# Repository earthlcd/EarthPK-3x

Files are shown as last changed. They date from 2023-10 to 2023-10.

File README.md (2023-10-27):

# EarthPK-3x Pico Pi Breakout Board for the 3x PCB



These are the design file for the EarthPK-3x Pico Pi Breakout Board that can be used with EarthLCD ezLCD-3x smart LCD's such asthe 3.5" ezLCD-303 and the ezLCD-304. Also this board with the mating DF-11 connector and the bare PCB along with a a bundled 4.3" ezLCD-3x is below: 

[ezLCD-3043-PK](https://earthlcd.com/products/ezlcd-3043-pk)

The arduino library to use the arduino IDE with this is below:

[arLCD Library](https://github.com/earthlcd/arLCDLib)

Schematic:
[REV-X2](https://github.com/earthlcd/EarthPK-3x/blob/master/schematics/ezLCD-303-PicoPi-Breakout-Board-REV-X2.pdf)

QuickStart Guide (coming soon)

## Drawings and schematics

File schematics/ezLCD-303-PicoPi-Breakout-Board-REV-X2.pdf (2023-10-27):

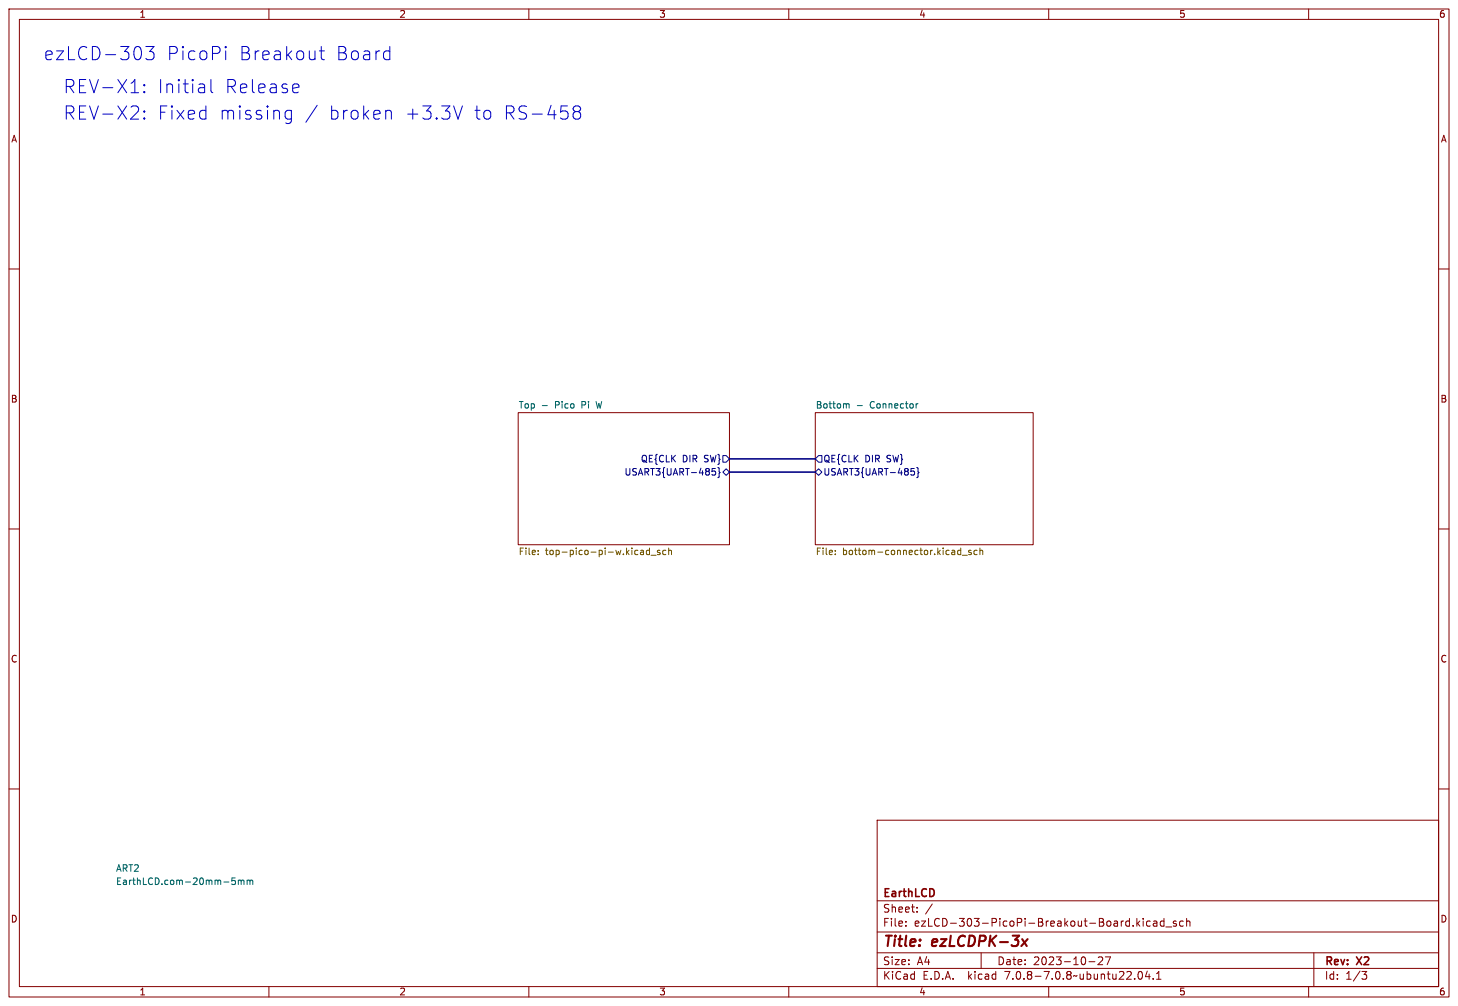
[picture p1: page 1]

QE{CLK DIR SW} Bottom - Connector File: bottom-connector.kicad_sch ART2 EarthLCD.com-20mm-5mm

QE{CLK DIR SW}
USART3{UART-485}

File: top-pico-pi-w.kicad_sch

File: ezLCD-303-PicoPi-Breakout-Board.kicad_sch Sheet: / EarthLCD

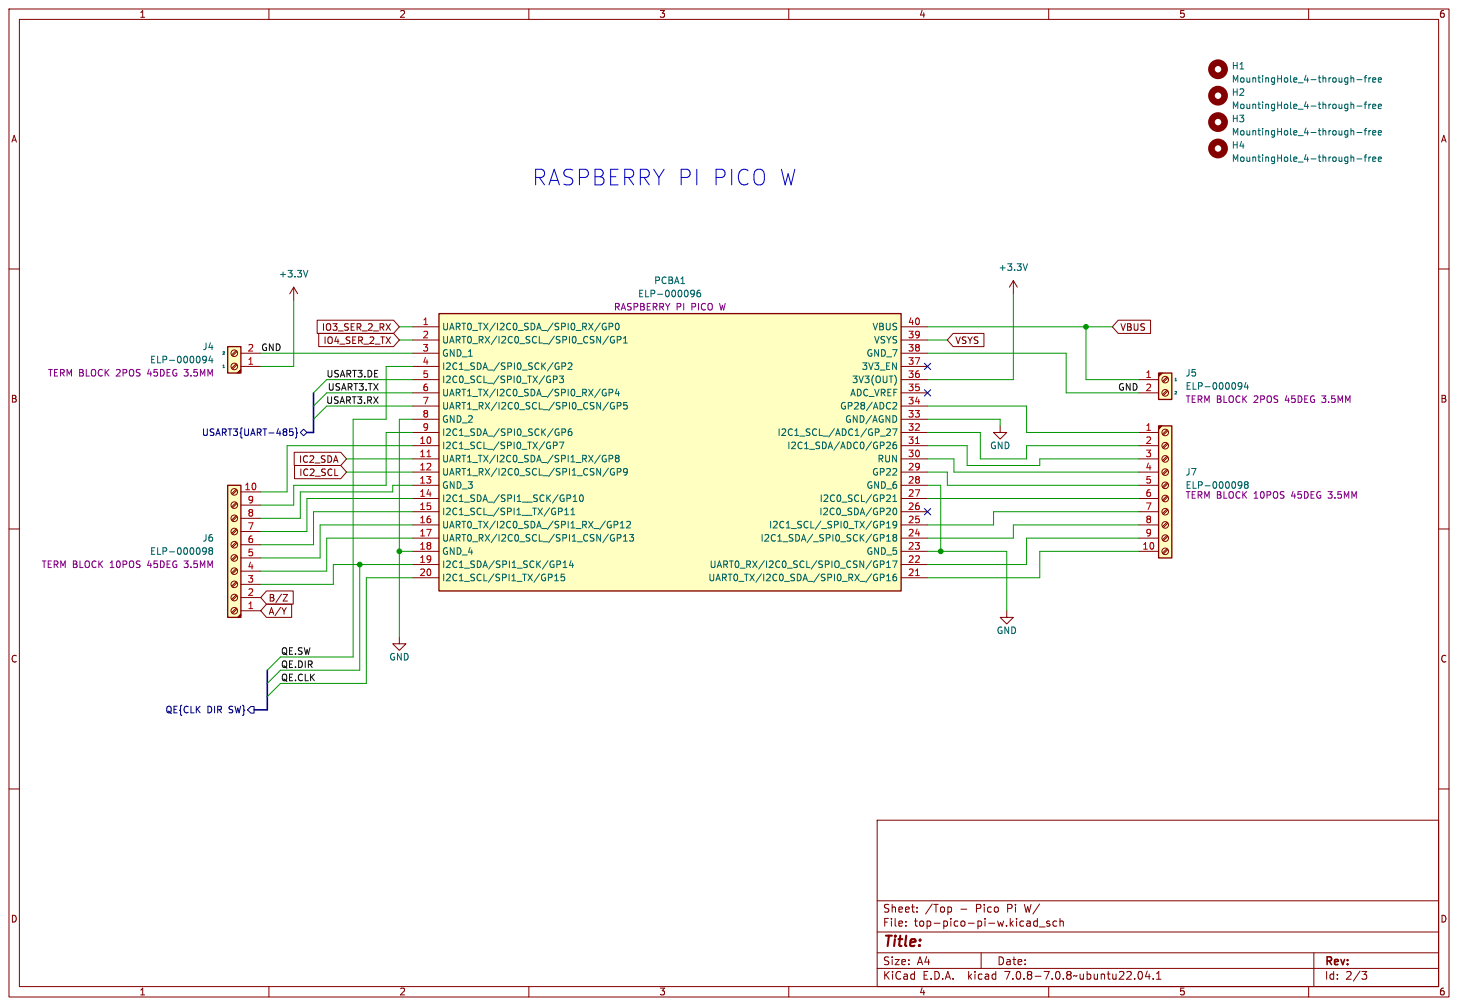
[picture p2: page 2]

H1 MountingHole_4-through-free H3 MountingHole_4-through-free H4 MountingHole_4-through-free H2 MountingHole_4-through-free

IC2_SDA QE.DIR QE.SW

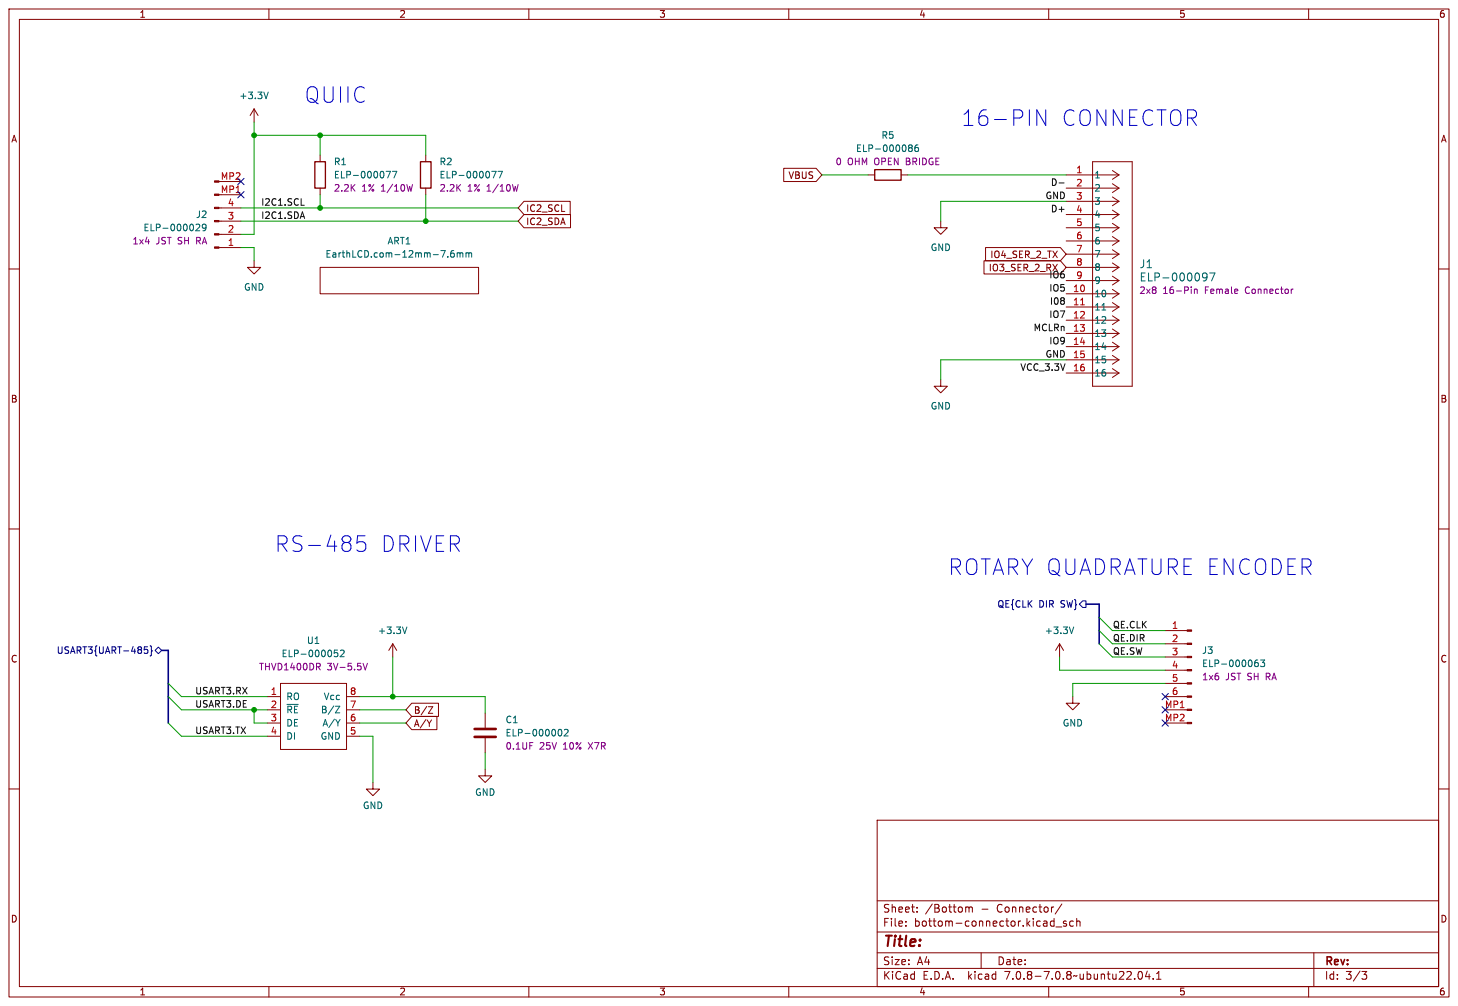
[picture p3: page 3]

QE{CLK DIR SW}

1x6 JST SH RA USART3{UART-485}

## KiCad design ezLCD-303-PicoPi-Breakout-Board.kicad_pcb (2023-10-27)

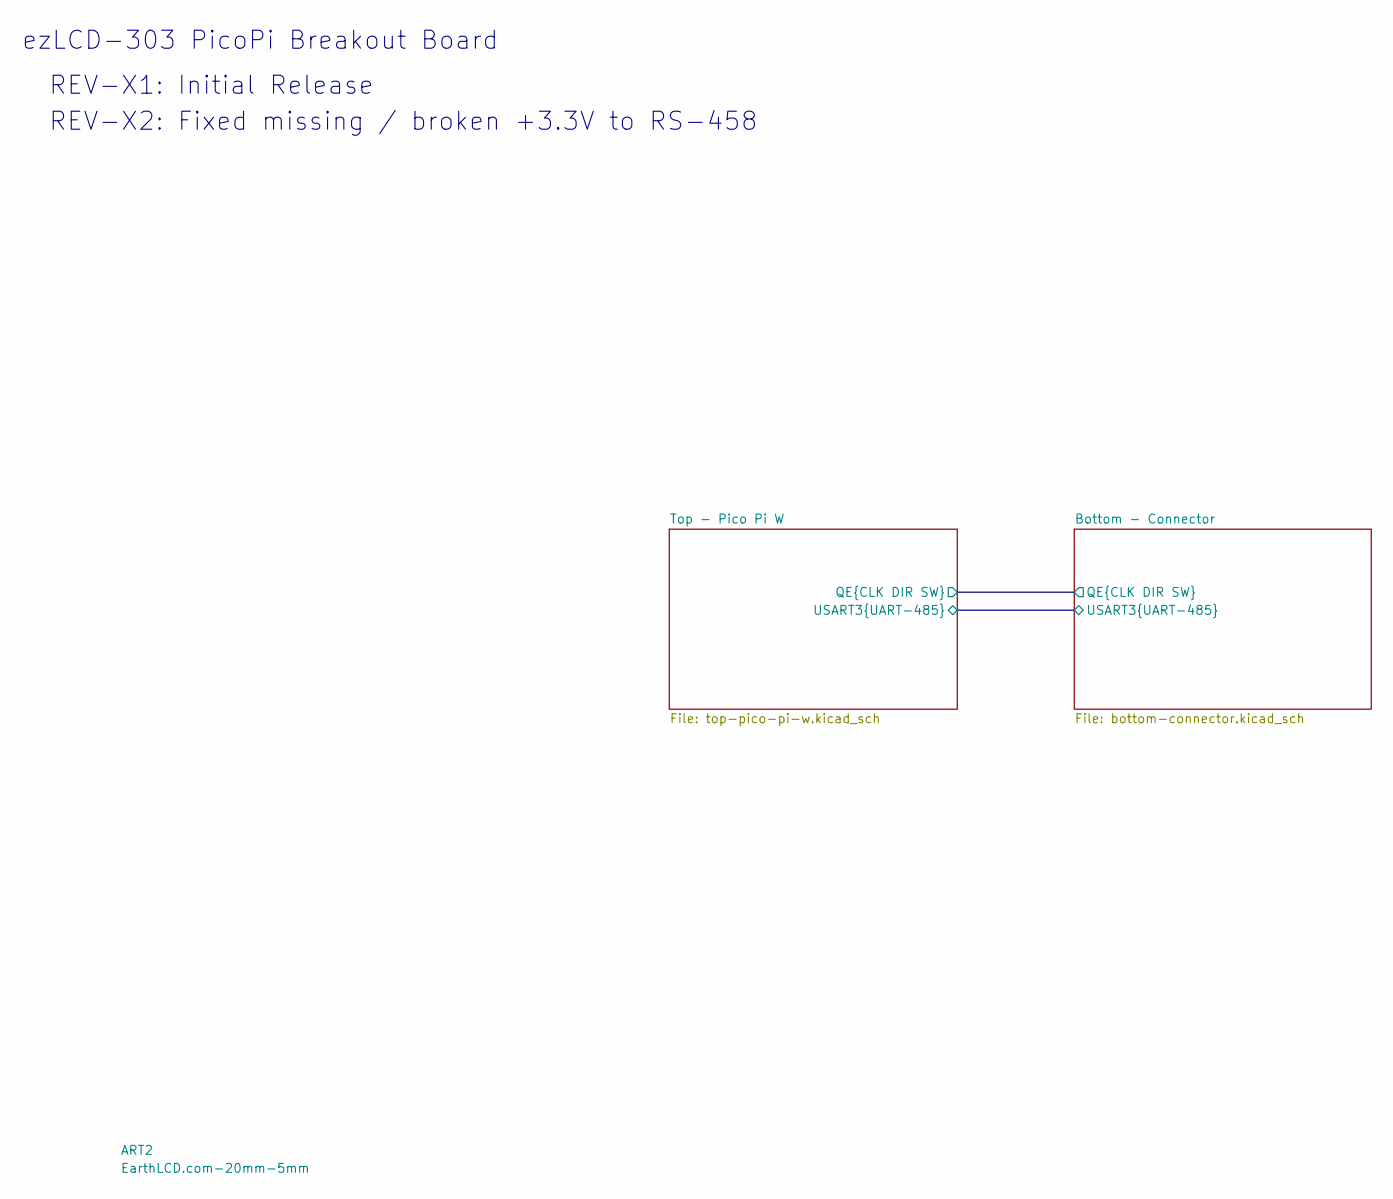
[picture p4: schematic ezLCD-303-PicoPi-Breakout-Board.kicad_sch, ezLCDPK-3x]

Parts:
ART2: EarthLCD.com-20mm-5mm; EarthLCD20mmX5mm

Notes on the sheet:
ezLCD-303 PicoPi Breakout Board
REV-X2: Fixed missing / broken +3.3V to RS-458
REV-X1: Initial Release

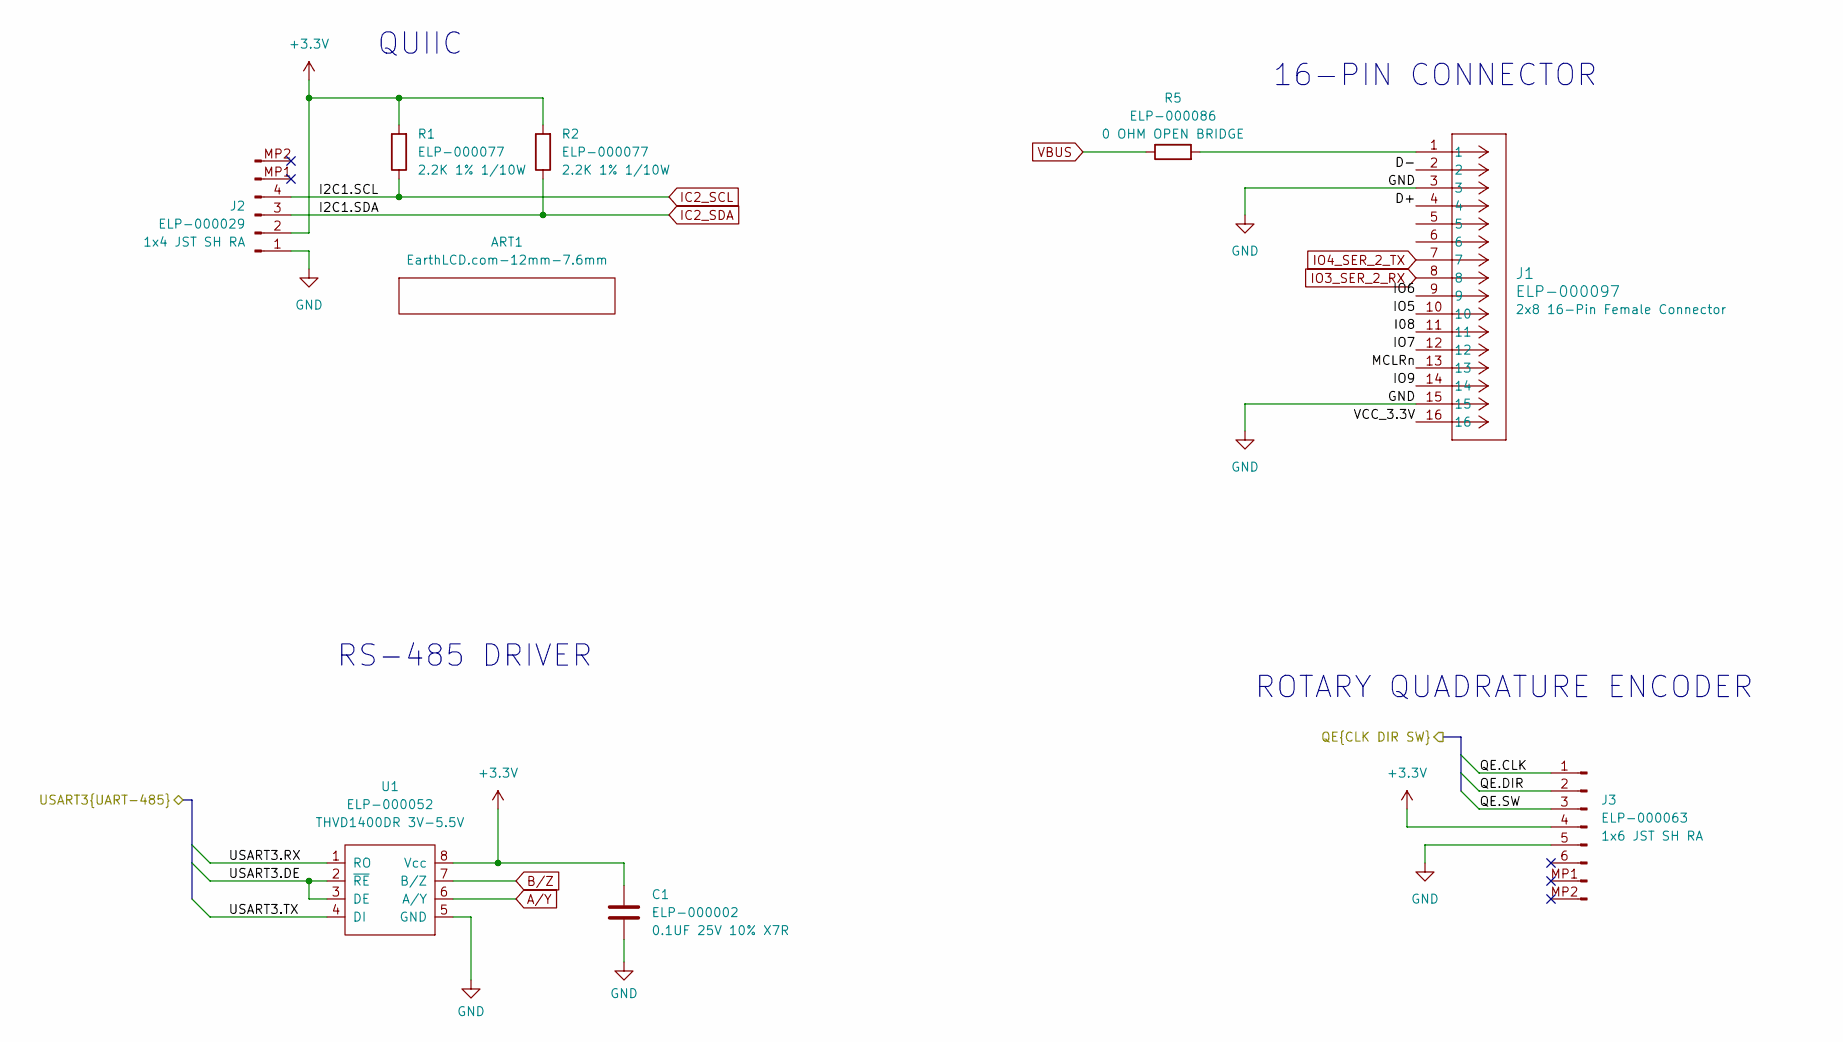
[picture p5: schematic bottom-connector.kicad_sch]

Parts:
ART1: EarthLCD.com-12mm-7.6mm; SparkFun-QWICC-Logo-4mm_x_1
C1: ELP-000002; C_0402_1005Metric
J1: ELP-000097
J2: ELP-000029; ELP-000029_JST_SH_SM04B-SRSS-TB_1x04-1MP_P1.00mm_Horizontal
J3: ELP-000063; ELP-000063_JST_SH_SM06B-SRSS-TB_1x06-1MP_P1.00mm_Horizontal
R1, R2: ELP-000077; R_0603_1608Metric
R5: ELP-000086
U1: ELP-000052; SO-8

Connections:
+3.3V: C1.1, J2.2, J3.4, R1.2, R2.2, U1.8 (Vcc); also elsewhere on the board
/Bottom - Connector/D+: J1.4
/Bottom - Connector/D-: J1.2
/Bottom - Connector/I08: J1.11
/Bottom - Connector/IO5: J1.10
/Bottom - Connector/IO6: J1.9
/Bottom - Connector/IO7: J1.12
/Bottom - Connector/IO9: J1.14
/Bottom - Connector/MCLRn: J1.13
/Bottom - Connector/QE.CLK: J3.1; also elsewhere on the board
/Bottom - Connector/QE.DIR: J3.2; also elsewhere on the board
/Bottom - Connector/QE.SW: J3.3; also elsewhere on the board
/Bottom - Connector/USART3.DE: U1.2 (~RE), U1.3 (DE)
/Bottom - Connector/USART3.RX: U1.1 (RO)
/Bottom - Connector/USART3.TX: U1.4 (DI)
/Bottom - Connector/VCC_3.3V: J1.16
A/Y: U1.6 (A/Y); also elsewhere on the board
B/Z: U1.7 (B/Z); also elsewhere on the board
GND: C1.2, J1.3, J1.15, J2.1, J3.5, U1.5 (GND); also elsewhere on the board
IC2_SCL: J2.4, R1.1; also elsewhere on the board
IC2_SDA: J2.3, R2.1; also elsewhere on the board
IO3_SER_2_RX: J1.8; also elsewhere on the board
IO4_SER_2_TX: J1.7; also elsewhere on the board
unnamed: J1.1, R5.2
VBUS: R5.1; also elsewhere on the board

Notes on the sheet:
RS-485 DRIVER
ROTARY QUADRATURE ENCODER
QUIIC
16-PIN CONNECTOR

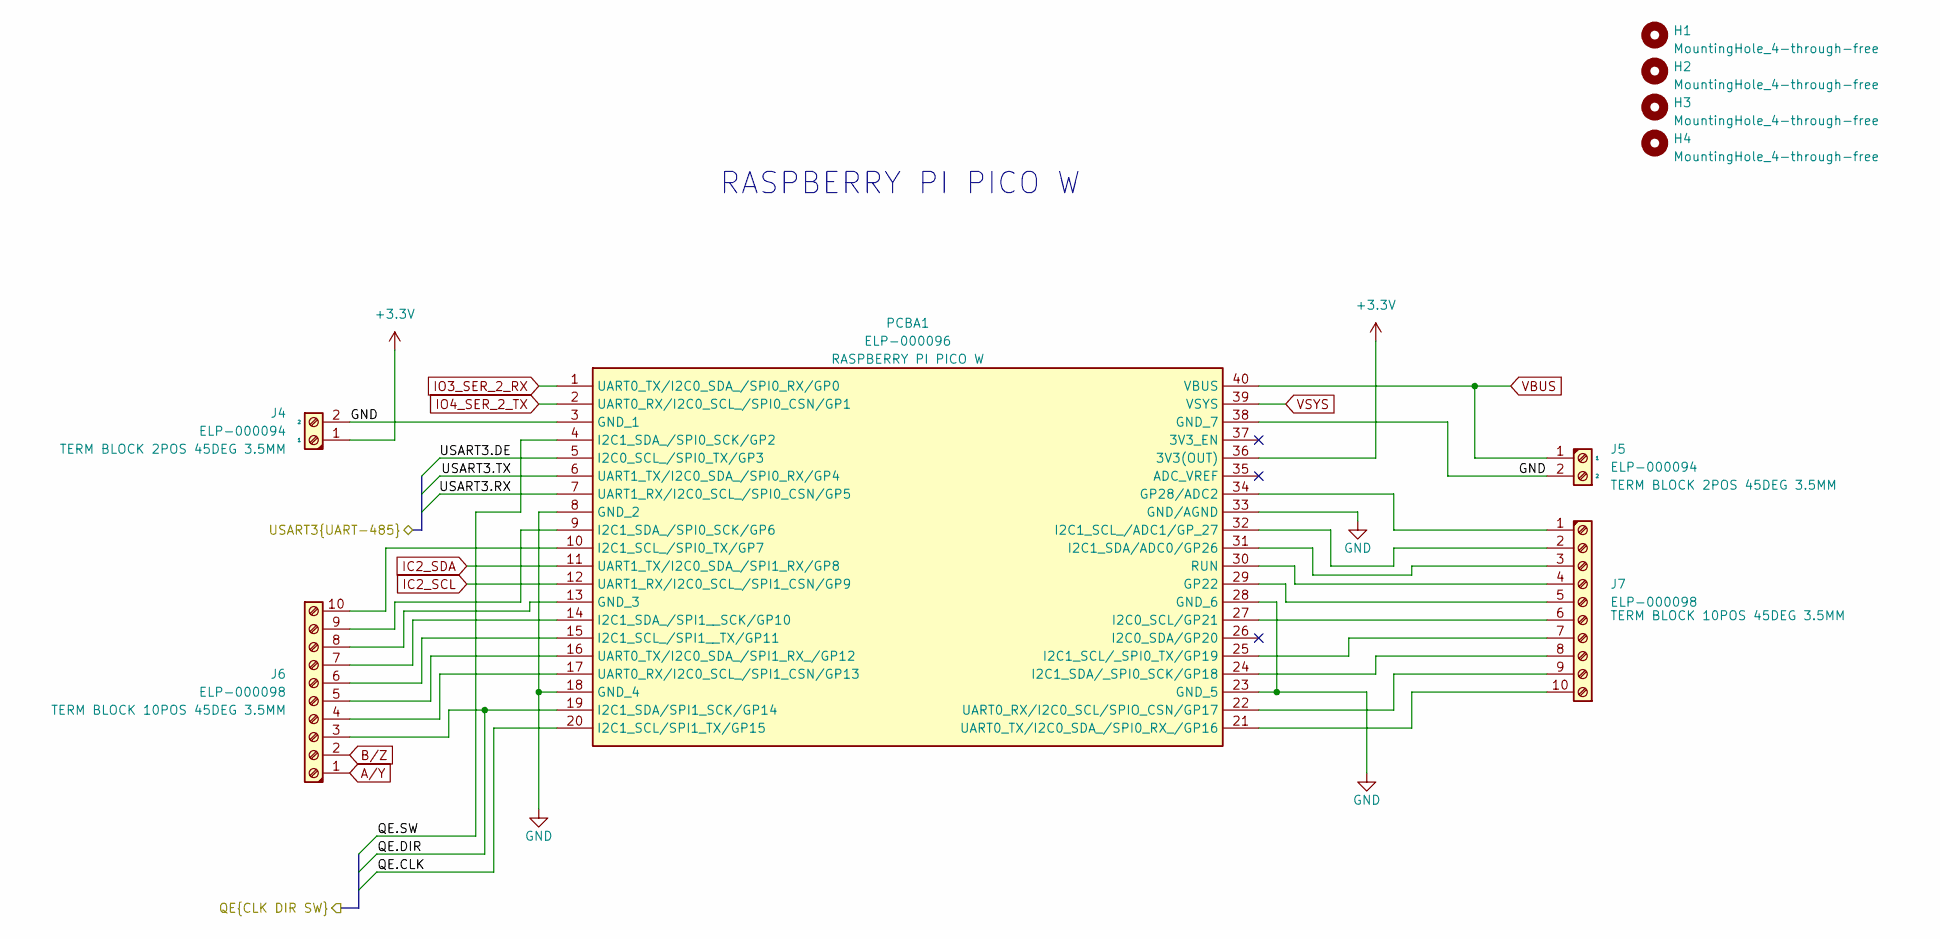
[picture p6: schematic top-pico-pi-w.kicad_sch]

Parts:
H1, H2, H3, H4: MountingHole_4-through-free
J4, J5: ELP-000094
J6, J7: ELP-000098
PCBA1: ELP-000096

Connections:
+3.3V: J4.1, PCBA1.36 (3V3(OUT)); also elsewhere on the board
/Bottom - Connector/QE.CLK: PCBA1.20 (I2C1_SCL/SPI1_TX/GP15); also elsewhere on the board
/Bottom - Connector/QE.DIR: J6.3, PCBA1.19 (I2C1_SDA/SPI1_SCK/GP14); also elsewhere on the board
/Bottom - Connector/QE.SW: PCBA1.4 (I2C1_SDA_/SPI0_SCK/GP2); also elsewhere on the board
/Top - Pico Pi W/USART3.DE: PCBA1.5 (I2C0_SCL_/SPI0_TX/GP3)
/Top - Pico Pi W/USART3.RX: PCBA1.7 (UART1_RX/I2C0_SCL_/SPI0_CSN/GP5)
/Top - Pico Pi W/USART3.TX: PCBA1.6 (UART1_TX/I2C0_SDA_/SPI0_RX/GP4)
A/Y: J6.1; also elsewhere on the board
B/Z: J6.2; also elsewhere on the board
GND: J4.2, J5.2, PCBA1.3 (GND_1), PCBA1.8 (GND_2), PCBA1.18 (GND_4), PCBA1.23 (GND_5), PCBA1.28 (GND_6), PCBA1.33 (GND/AGND), PCBA1.38 (GND_7); also elsewhere on the board
IC2_SCL: PCBA1.12 (UART1_RX/I2C0_SCL_/SPI1_CSN/GP9); also elsewhere on the board
IC2_SDA: PCBA1.11 (UART1_TX/I2C0_SDA_/SPI1_RX/GP8); also elsewhere on the board
IO3_SER_2_RX: PCBA1.1 (UART0_TX/I2C0_SDA_/SPI0_RX/GP0); also elsewhere on the board
IO4_SER_2_TX: PCBA1.2 (UART0_RX/I2C0_SCL_/SPI0_CSN/GP1); also elsewhere on the board
unnamed: J6.4, PCBA1.17 (UART0_RX/I2C0_SCL_/SPI1_CSN/GP13)
unnamed: J6.5, PCBA1.16 (UART0_TX/I2C0_SDA_/SPI1_RX_/GP12)
unnamed: J6.6, PCBA1.15 (I2C1_SCL_/SPI1__TX/GP11)
unnamed: J6.7, PCBA1.14 (I2C1_SDA_/SPI1__SCK/GP10)
unnamed: J6.8, PCBA1.13 (GND_3)
unnamed: J6.9, PCBA1.9 (I2C1_SDA_/SPI0_SCK/GP6)
unnamed: J6.10, PCBA1.10 (I2C1_SCL_/SPI0_TX/GP7)
unnamed: J7.1, PCBA1.34 (GP28/ADC2)
unnamed: J7.2, PCBA1.32 (I2C1_SCL_/ADC1/GP_27)
unnamed: J7.3, PCBA1.31 (I2C1_SDA/ADC0/GP26)
unnamed: J7.4, PCBA1.30 (RUN)
unnamed: J7.5, PCBA1.29 (GP22)
unnamed: J7.6, PCBA1.27 (I2C0_SCL/GP21)
unnamed: J7.7, PCBA1.25 (I2C1_SCL/_SPI0_TX/GP19)
unnamed: J7.8, PCBA1.24 (I2C1_SDA/_SPI0_SCK/GP18)
unnamed: J7.9, PCBA1.22 (UART0_RX/I2C0_SCL/SPIO_CSN/GP17)
unnamed: J7.10, PCBA1.21 (UART0_TX/I2C0_SDA_/SPI0_RX_/GP16)
VBUS: J5.1, PCBA1.40 (VBUS); also elsewhere on the board
VSYS: PCBA1.39 (VSYS)

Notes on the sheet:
RASPBERRY PI PICO W

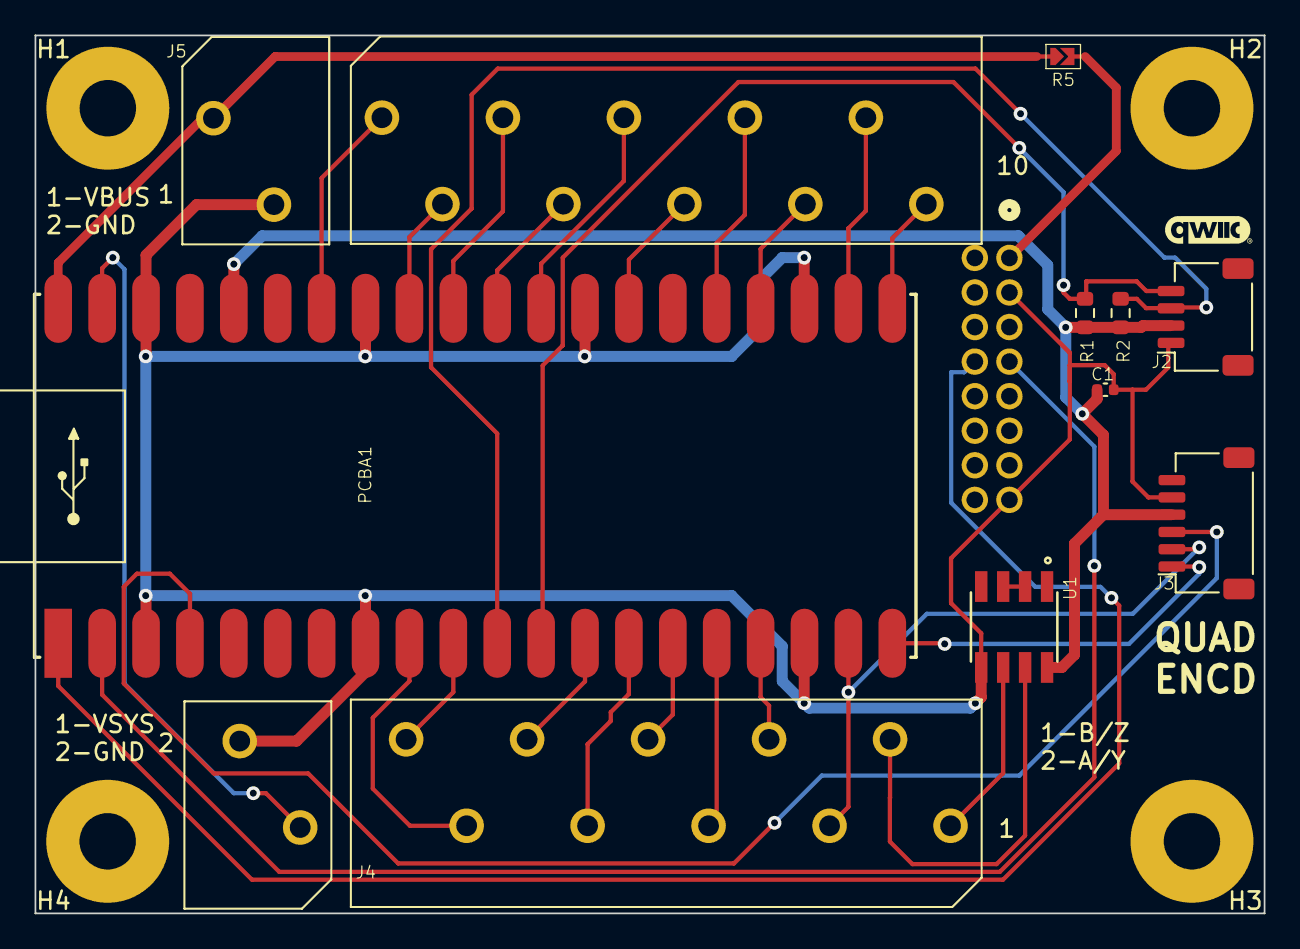
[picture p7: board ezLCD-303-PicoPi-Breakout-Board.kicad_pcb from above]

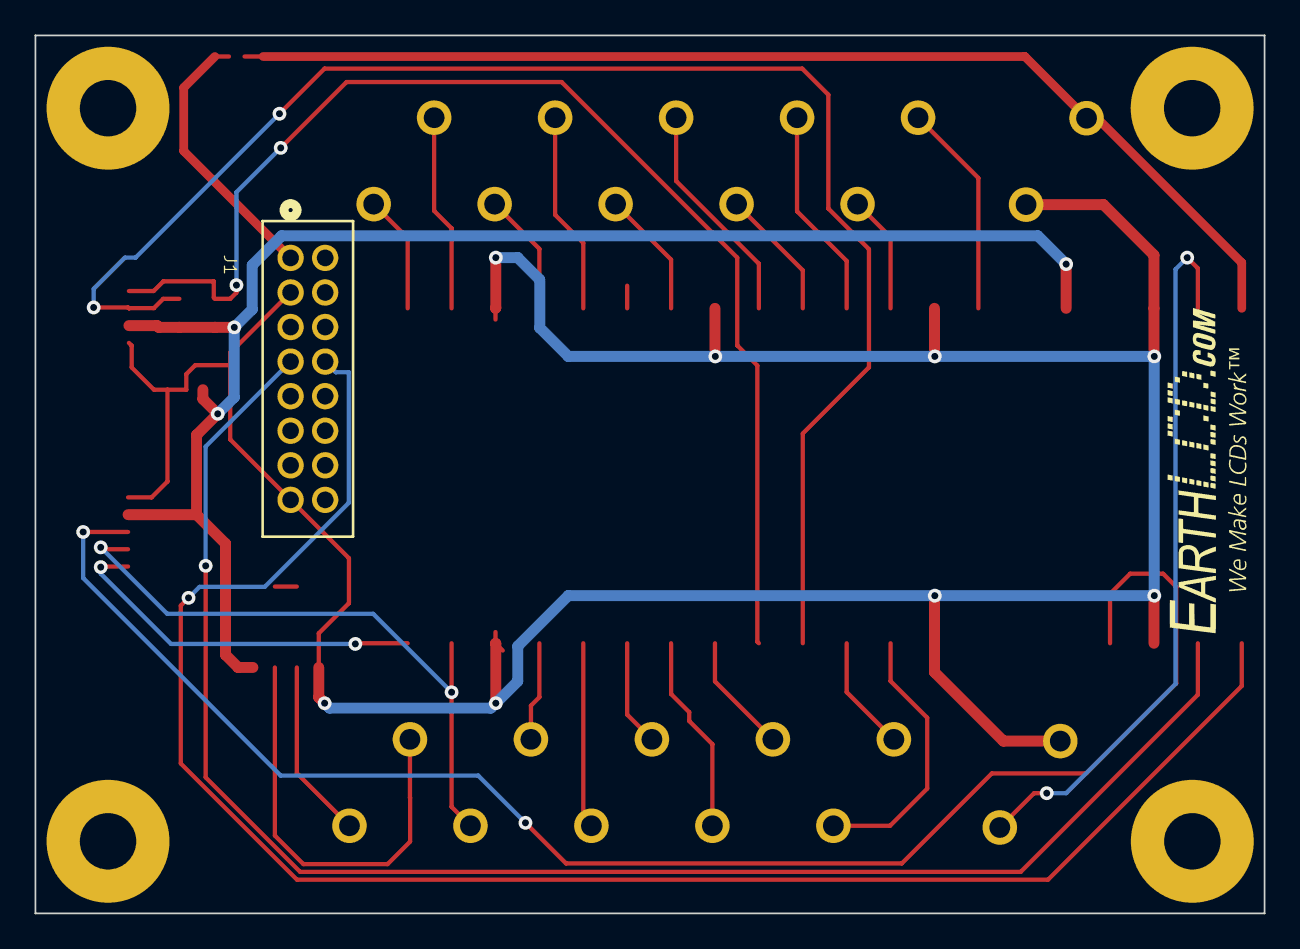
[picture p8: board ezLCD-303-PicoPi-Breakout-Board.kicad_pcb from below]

Board: 2 copper layers, 71.1 x 50.8 mm, 19 parts (2 on the bottom side), 31 nets.

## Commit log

2023-10-14 Initial commit.
    [bottom-connector.kicad_sch, ezLCD-303-PicoPi-Breakout-Board.kicad_pcb, ezLCD-303-PicoPi-Breakout-Board.kicad_sch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]
2023-10-14 Adjusted origins on the PCB
    [ezLCD-303-PicoPi-Breakout-Board.kicad_pcb]
2023-10-14 Added additional silk to help indicate connection points.
    [ezLCD-303-PicoPi-Breakout-Board.kicad_pcb]
2023-10-14 After Generating Gerbers (X1)
    [ezLCD-303-PicoPi-Breakout-Board.kicad_pcb]
2023-10-14 Added REV-X1 Gerbers
2023-10-14 Some how, the gerbers didn't get added to the zip.
2023-10-27 Fixed errors on the schematic found after fabrication of the X1 PCB's.
    [bottom-connector.kicad_sch, ezLCD-303-PicoPi-Breakout-Board.kicad_pcb, ezLCD-303-PicoPi-Breakout-Board.kicad_sch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]
